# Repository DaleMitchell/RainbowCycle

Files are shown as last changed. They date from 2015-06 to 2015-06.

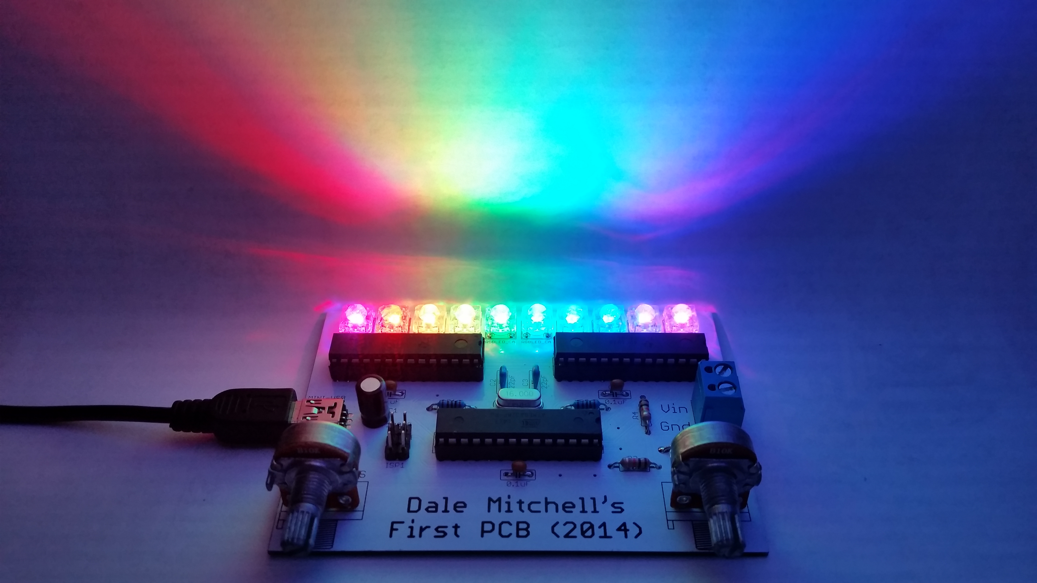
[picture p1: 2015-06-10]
pictures/RainbowCycle_Assembled_Board.jpg

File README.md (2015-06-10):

# RainbowCycle
My very first circuit board. I'm very proud to say that the first fabrication of it worked! :)

The PCB was fabricated by Seeedstudio: http://www.seeedstudio.com/service/

Components on the board were hand soldered by me.

## YouTube Video
<a href="http://www.youtube.com/watch?feature=player_embedded&v=ZXkaFkIlUeY
" target="_blank">RainbowCycle YouTube Video</a>

## Bill of materials
* 10x Common Anode RGB LEDs - 5mm Square (Sometimes called 'Super flux' or 'Piranha') 
* 1x ATMega328P-PU - same chip used by the Arduino Uno
* 2x TLC5940s - 16 Channel LED Driver
* 2x 10K Ohm Potentiometers - adjustable speed and brightness
* 2x 2K Ohm Resistors - current limiting for LED drivers
* 2x 10K Ohm Resistors - pull-up resistors for the ICs
* 1x 100uF Capacitor - filtering capacitor for stable power to ICs
* 3x 0.1uF Capacitors - also filtering capacitors for each IC
* 1x 16MHz Crystal - clock input for ATMega328P-PU
* 2x 22pF Capacitors - used by the 16MHz crystal
* 1x Mini-USB Connector - for power only, doesn't program Arduino
* 1x ISP Header - for programming the ATMega328P-PU
* 1x Terminal Blocks 5.08mm - alternative connector for power
* 1x Diode - protection against reverse polarity on block terminal

## Things I'd do differently if I wanted to revise the board

* Use trimpots that are flush with the board instead of panel mount potentiometers. Even when soldered on both sides of the board, the currently used potentiometers bend easily.
* Replace ATMega328P-PU with a microcontroller that can be programmed directly through USB. ICSP was a hassle, and I couldn't find a through-hole means of converting USB to serial.
* Provide overvoltage protection, or at least put a warning on the silkscreen that the circuit is only rated for 5V.
* Make pads on some components slightly bigger for some components, like resistors and small capacitors.
* Use slightly higher clearance for ground plane (maybe?).

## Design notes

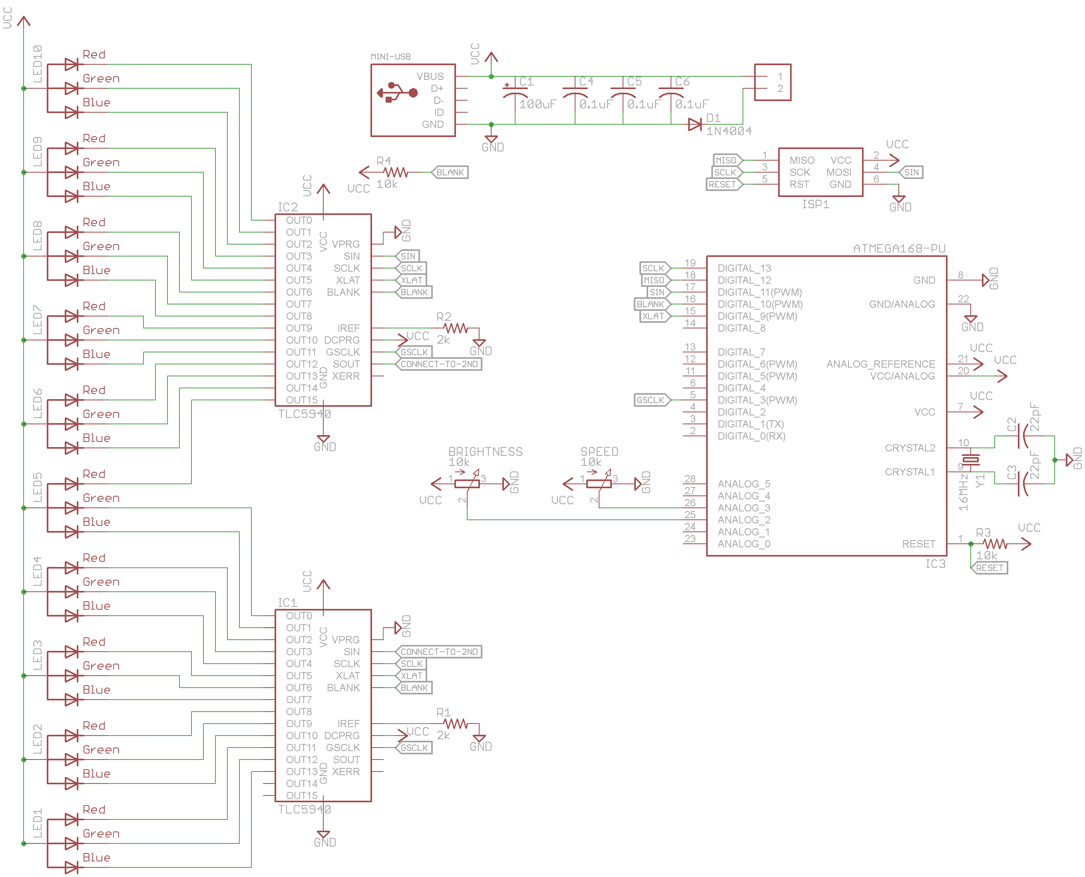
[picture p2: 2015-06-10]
pictures/RainbowCycle_Schematic.png

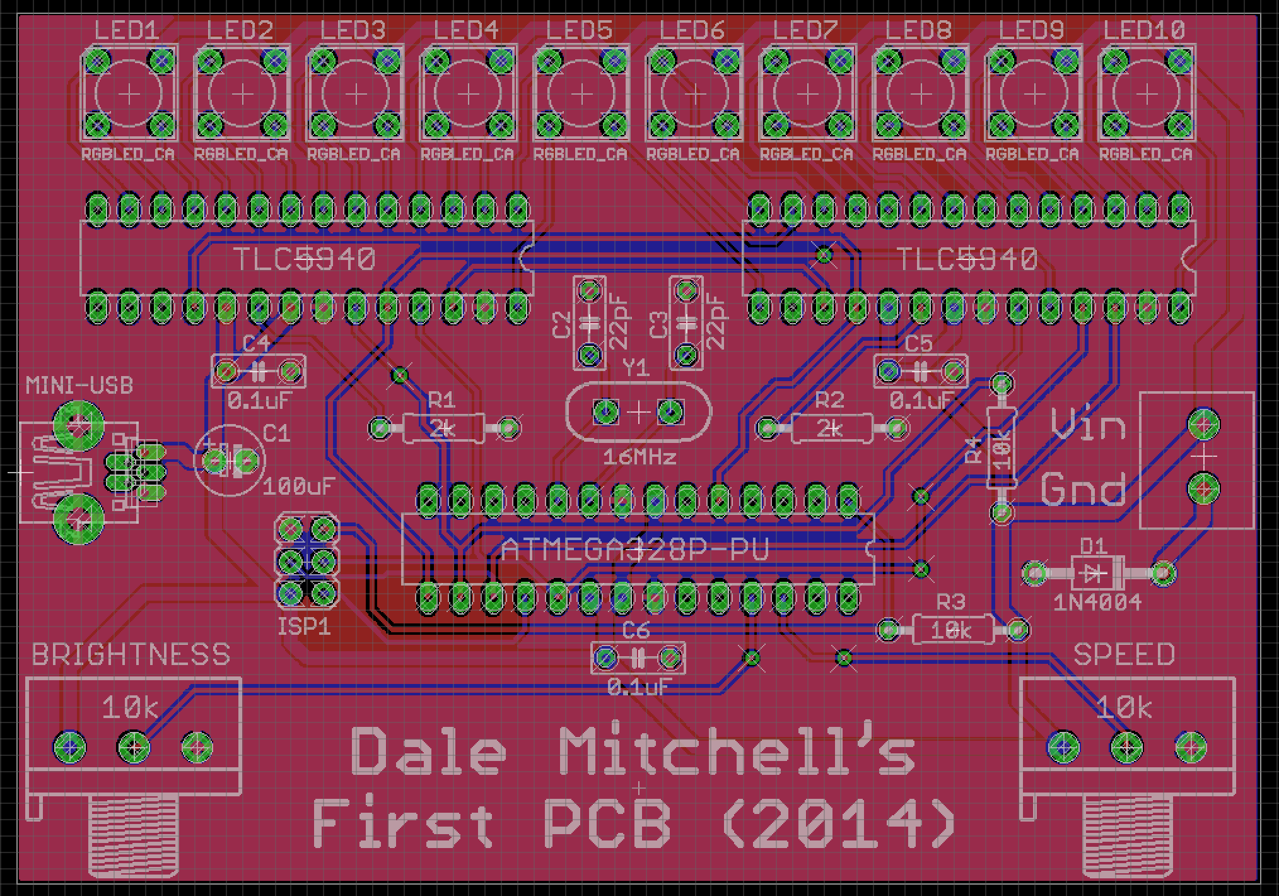
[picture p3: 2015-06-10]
pictures/RainbowCycle_Board.png

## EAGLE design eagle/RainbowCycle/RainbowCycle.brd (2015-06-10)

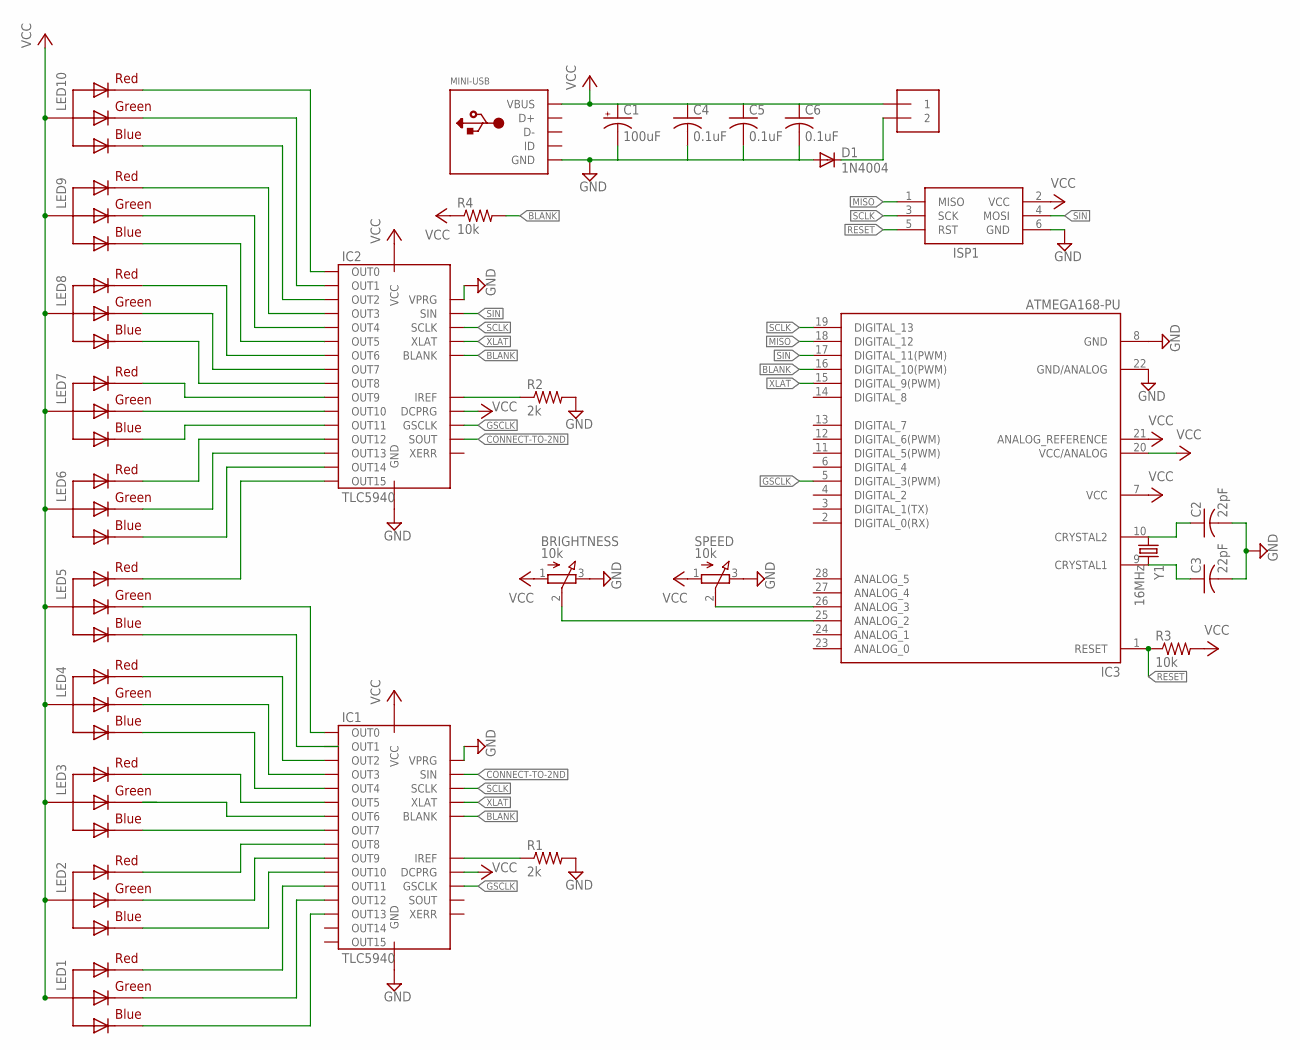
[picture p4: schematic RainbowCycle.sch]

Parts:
BLOCK-TERMINAL: 1X2-5.08MM
BRIGHTNESS: 10k; 3RP/1610N
C1: 100uF; E2,5-6
C2, C3: 22pF; C050-025X075
C4, C5, C6: 0.1uF; C050-025X075
D1: 1N4004; DO41-10
IC1, IC2: TLC5940; IC-PACKAGE_DIL28-3
IC3: ATMEGA168-PU; DIL28-3
ISP1: AVRISP-6; AVRISP
LED1, LED2, LED3, LED4, LED5, LED6, LED7, LED8, LED9, LED10: RGBLED_CA; PIRANHA5MM
MINI-USB: USBMOLEX; USB-MINIB-THM-MOLEX
R1, R2: 2k; 0207/10
R3, R4: 10k; 0207/10
SPEED: 10k; 3RP/1610N
Y1: 16MHz; HC49US

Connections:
BLANK: IC1.23 (BLANK), IC2.23 (BLANK), IC3.16 (DIGITAL_10(PWM)), R4.2
CONNECT-TO-2ND: IC1.26 (SIN), IC2.17 (SOUT)
GND: BRIGHTNESS.3 (E), C1.-, C2.2, C3.2, C4.2, C5.2, C6.2, D1.A, IC1.22 (GND), IC1.27 (VPRG), IC2.22 (GND), IC2.27 (VPRG), IC3.8 (GND), IC3.22 (GND/ANALOG), ISP1.6 (GND), MINI-USB.GND, MINI-USB.GND1 (GND), MINI-USB.GND4 (GND), R1.2, R2.2, SPEED.3 (E)
GSCLK: IC1.18 (GSCLK), IC2.18 (GSCLK), IC3.5 (DIGITAL_3(PWM))
MISO: IC3.18 (DIGITAL_12), ISP1.1 (MISO)
unnamed: BRIGHTNESS.2 (S), IC3.25 (ANALOG_2)
unnamed: IC3.26 (ANALOG_3), SPEED.2 (S)
unnamed: IC2.20 (IREF), R2.1
unnamed: BLOCK-TERMINAL.2, D1.C
unnamed: C3.1, IC3.9 (CRYSTAL1), Y1.2
unnamed: C2.1, IC3.10 (CRYSTAL2), Y1.1
unnamed: IC2.28 (OUT0), LED10.3 (RED)
unnamed: IC1.1 (OUT1), LED5.1 (BLUE)
unnamed: IC2.1 (OUT1), LED10.2 (GREEN)
unnamed: IC2.2 (OUT2), LED10.1 (BLUE)
unnamed: IC1.20 (IREF), R1.1
unnamed: IC2.3 (OUT3), LED9.3 (RED)
unnamed: IC2.4 (OUT4), LED9.2 (GREEN)
unnamed: IC2.5 (OUT5), LED9.1 (BLUE)
unnamed: IC2.6 (OUT6), LED8.3 (RED)
unnamed: IC2.7 (OUT7), LED8.2 (GREEN)
unnamed: IC2.8 (OUT8), LED8.1 (BLUE)
unnamed: IC2.9 (OUT9), LED7.3 (RED)
unnamed: IC2.10 (OUT10), LED7.2 (GREEN)
unnamed: IC2.11 (OUT11), LED7.1 (BLUE)
unnamed: IC2.12 (OUT12), LED6.3 (RED)
unnamed: IC2.13 (OUT13), LED6.2 (GREEN)
unnamed: IC2.14 (OUT14), LED6.1 (BLUE)
unnamed: IC2.15 (OUT15), LED5.3 (RED)
unnamed: IC1.28 (OUT0), LED5.2 (GREEN)
unnamed: IC1.13 (OUT13), LED1.1 (BLUE)
unnamed: IC1.2 (OUT2), LED4.3 (RED)
unnamed: IC1.3 (OUT3), LED4.2 (GREEN)
unnamed: IC1.4 (OUT4), LED4.1 (BLUE)
unnamed: IC1.5 (OUT5), LED3.3 (RED)
unnamed: IC1.6 (OUT6), LED3.2 (GREEN)
unnamed: IC1.7 (OUT7), LED3.1 (BLUE)
unnamed: IC1.12 (OUT12), LED1.2 (GREEN)
unnamed: IC1.11 (OUT11), LED1.3 (RED)
unnamed: IC1.10 (OUT10), LED2.1 (BLUE)
unnamed: IC1.9 (OUT9), LED2.2 (GREEN)
unnamed: IC1.8 (OUT8), LED2.3 (RED)
RESET: IC3.1 (RESET), ISP1.5 (RST), R3.1
SCLK: IC1.25 (SCLK), IC2.25 (SCLK), IC3.19 (DIGITAL_13), ISP1.3 (SCK)
SIN: IC2.26 (SIN), IC3.17 (DIGITAL_11(PWM)), ISP1.4 (MOSI)
VCC: BLOCK-TERMINAL.1, BRIGHTNESS.1 (A), C1.+, C4.1, C5.1, C6.1, IC1.19 (DCPRG), IC1.21 (VCC), IC2.19 (DCPRG), IC2.21 (VCC), IC3.7 (VCC), IC3.20 (VCC/ANALOG), IC3.21 (ANALOG_REFERENCE), ISP1.2 (VCC), LED1.4 (VCC), LED2.4 (VCC), LED3.4 (VCC), LED4.4 (VCC), LED5.4 (VCC), LED6.4 (VCC), LED7.4 (VCC), LED8.4 (VCC), LED9.4 (VCC), LED10.4 (VCC), MINI-USB.VBUS, R3.2, R4.1, SPEED.1 (A)
XLAT: IC1.24 (XLAT), IC2.24 (XLAT), IC3.15 (DIGITAL_9(PWM))

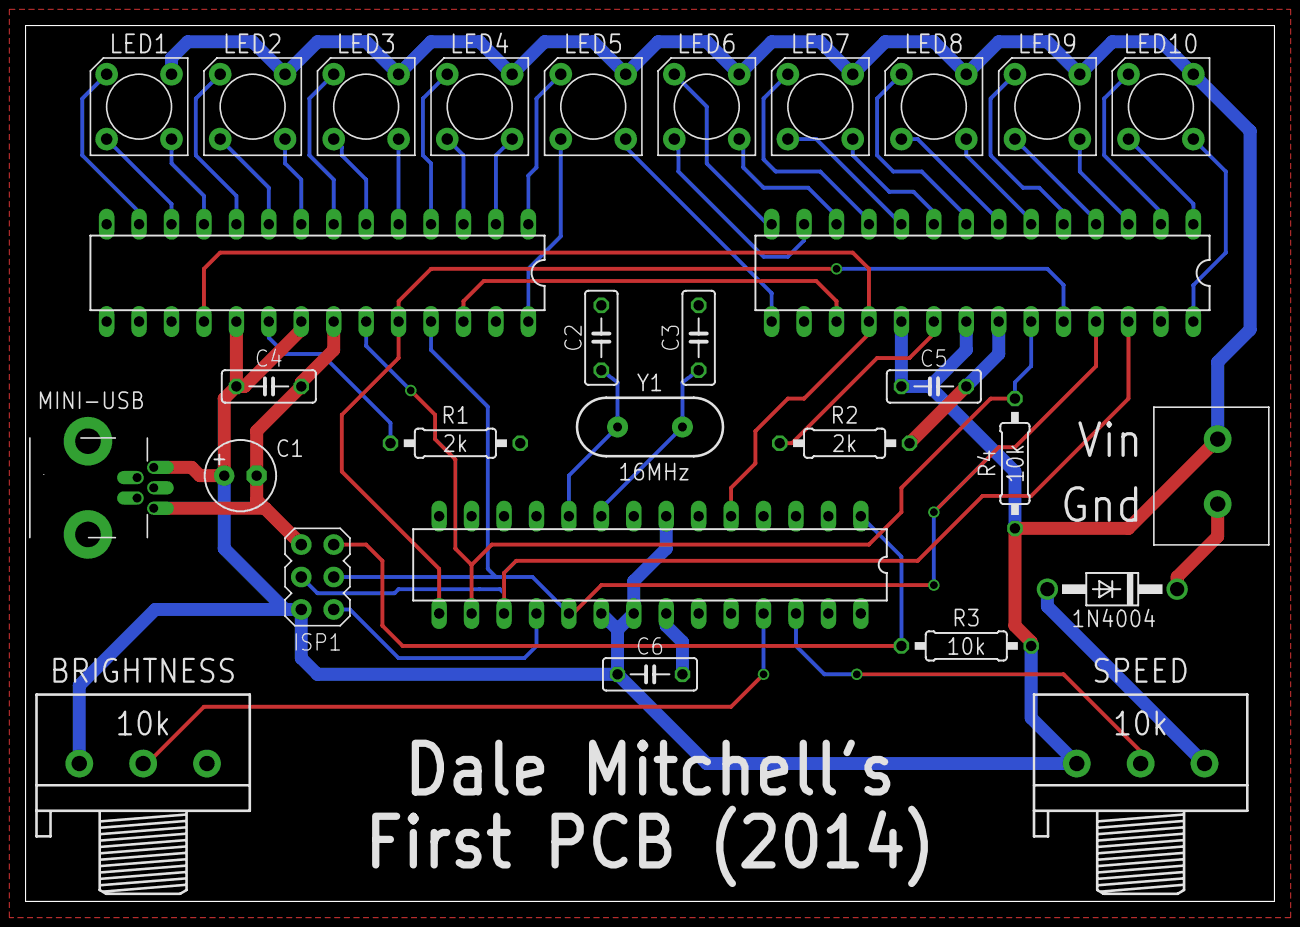
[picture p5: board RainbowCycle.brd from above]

Board: 4 copper layers, 97.8 x 68.6 mm, 30 parts (0 on the bottom side), 47 nets.

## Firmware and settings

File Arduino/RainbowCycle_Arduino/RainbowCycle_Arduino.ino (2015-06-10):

/*
Source code for RainbowCycle - Dale's First PCB
Controls 10 RGB LEDs with two TLC5940s and one ATMega328P-PU
Also has two potentiometers for manipulating brightness and speed of the color wheel

* Important: this code depends on the tlc5940arduino library. * 
http://code.google.com/p/tlc5940arduino/downloads/list
*/

#include "Tlc5940.h" // This is required, don't forget it :P

// Experimental "Faster Analog" Code
#define FASTADC 1
// defines for setting and clearing register bits
#ifndef cbi
#define cbi(sfr, bit) (_SFR_BYTE(sfr) &= ~_BV(bit))
#endif
#ifndef sbi
#define sbi(sfr, bit) (_SFR_BYTE(sfr) |= _BV(bit))
#endif
// End Experimental "Faster Analog" Code

#define NUM_LEDS 10                   // number of RGB LEDs controlled

struct RGB { byte r; byte g; byte b; };
RGB rgb;

// Potentiometers 
const int brightness_pot_pin = A2;    // analog input pin that the brightness potentiometer is attached to
const int speed_pot_pin = A3;         // analog input pin that the speed potentiometer is attached to

int brightness_pot = 0;               // raw value read from brightness potentiometer
int brightness_mapped = 0;            // mapped value from brightness potentiometer
int speed_pot = 0;                    // raw value read from speed potentiometer
int speed_mapped = 0;                 // mapped value from speed potentiometer

void setup(){
  
// More Experimental "Faster Analog" Code
  #if FASTADC
  // set prescale to 16
  sbi(ADCSRA,ADPS2);
  cbi(ADCSRA,ADPS1);
  cbi(ADCSRA,ADPS0);
  #endif
// End Experimental "Faster Analog" Code
  Tlc.init();  
}

void loop(){

  randomSeed(millis());

  int dim=random(4,6);
  int max_cycles=0;
  int cycles=-1;

  rainbowCycle(speed_mapped,cycles,dim);

}

void setLed(byte num,int red,int green,int blue){

  if(brightness_mapped){
    red=red/brightness_mapped;
    green=green/brightness_mapped;
    blue=blue/brightness_mapped;
  }

  Tlc.set(num*3,red);
  Tlc.set(num*3+1,green);
  Tlc.set(num*3+2,blue);

} 

void rainbowCycle(uint8_t speed_mapped,byte cycle,byte dim) {

  int cycles, j, k;

  for(cycles=0;cycles<cycle;cycles++){

    byte dir=0;
    k=255;

    for (j=0; j < 256; j++,k--) {
      // read the "analog in" values:
      brightness_pot = analogRead(brightness_pot_pin);
      speed_pot = analogRead(speed_pot_pin);

      // map the readings to their appropriate ranges
      brightness_mapped = map(brightness_pot, 1, 1023, 1, 48);
      speed_mapped = map(speed_pot, 0, 1023, 0.1, 30);

      if(k<0)k=255;

      for(int i=0; i<NUM_LEDS; i+=1) {
        // read the "analog in" values:
        brightness_pot = analogRead(brightness_pot_pin);
        speed_pot = analogRead(speed_pot_pin);

        // map the readings to their appropriate ranges
        brightness_mapped = map(brightness_pot, 1, 1023, 1, 48);
        speed_mapped = map(speed_pot, 0, 1023, 0.1, 30);

        int brightness_mapped = brightness_mapped; 
        Wheel(((i * 256 / NUM_LEDS) + (dir==0?j:k)) % 256,dim);

        setLed(i,rgb.r*32,rgb.g*32,rgb.b*32);

      }
      Tlc.update();
      delay(speed_mapped);
    }
  }
}

void Wheel(byte WheelPos,byte dim){

  if (WheelPos < 85) {
    rgb.r=0;
    rgb.g=WheelPos * 3/dim;
    rgb.b=(255 - WheelPos * 3)/dim;;
    return;
  } 
  else if (WheelPos < 170) {
    WheelPos -= 85;
    rgb.r=WheelPos * 3/dim;
    rgb.g=(255 - WheelPos * 3)/dim;
    rgb.b=0;
    return;
  }
  else {
    WheelPos -= 170; 
    rgb.r=(255 - WheelPos * 3)/dim;
    rgb.g=0;
    rgb.b=WheelPos * 3/dim;
    return;
  }
}

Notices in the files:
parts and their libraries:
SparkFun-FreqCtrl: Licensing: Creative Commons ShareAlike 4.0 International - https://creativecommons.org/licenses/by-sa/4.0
